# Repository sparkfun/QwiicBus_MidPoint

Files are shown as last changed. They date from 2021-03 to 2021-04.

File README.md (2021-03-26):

SparkFun QwiicBus MidPoint
========================================

SparkFun QwiicBus MidPoint (https://www.sparkfun.com/products/18000)

[*SparkFun QwiicBus MidPoint (COM-18000)*](https://www.sparkfun.com/products/18000)

The SparkFun QwiicBus MidPoint works in tandem with the [SparkFun QwiicBus EndPoint](https://www.sparkfun.com/products/16988) to drop in I<sup>2</sup>C connections into a long-distance wired differential I<sup>2</sup>C bus. 
Featuring the PCA9615, the MidPoint translates a standard two-wire I<sup>2</sup>C signal to a 4-wire differential signal to allow long-distance and/or isolated wired buses. The board also includes a buck regulator that can be enabled to combat voltage drop over long distances as well as deliver more current to attached devices.

Repository Contents
-------------------

* **/Hardware** - Eagle design files (.brd, .sch)
* **/Production** - Production panel files (.brd)

Documentation
--------------
* **[Hookup Guide](https://learn.sparkfun.com/tutorials/sparkfun-qwiicbus-hookup-guide)** - Basic hookup guide for the SparkFun QwiicBus (MidPoint and EndPoint).

Product Versions
----------------
* [COM-18000](https://www.sparkfun.com/products/18000)- Initial QwiicBus MidPoint release
* [COM-16988](https://www.sparkfun.com/products/16988) - QwiicBus EndPoint initial release
* [KIT-17250](https://www.sparkfun.com/products/17250) - The SparkFun QwiicBus Kit includes 2 EndPoints, 1 MidPoint and a pair of Ethernet cables to get started with the QwiicBus.

License Information
-------------------

This product is _**open source**_! 

Please review the LICENSE.md file for license information. 

If you have any questions or concerns on licensing, please contact technical support on our [SparkFun forums](https://forum.sparkfun.com/viewforum.php?f=152).

Distributed as-is; no warranty is given.

- Your friends at SparkFun.

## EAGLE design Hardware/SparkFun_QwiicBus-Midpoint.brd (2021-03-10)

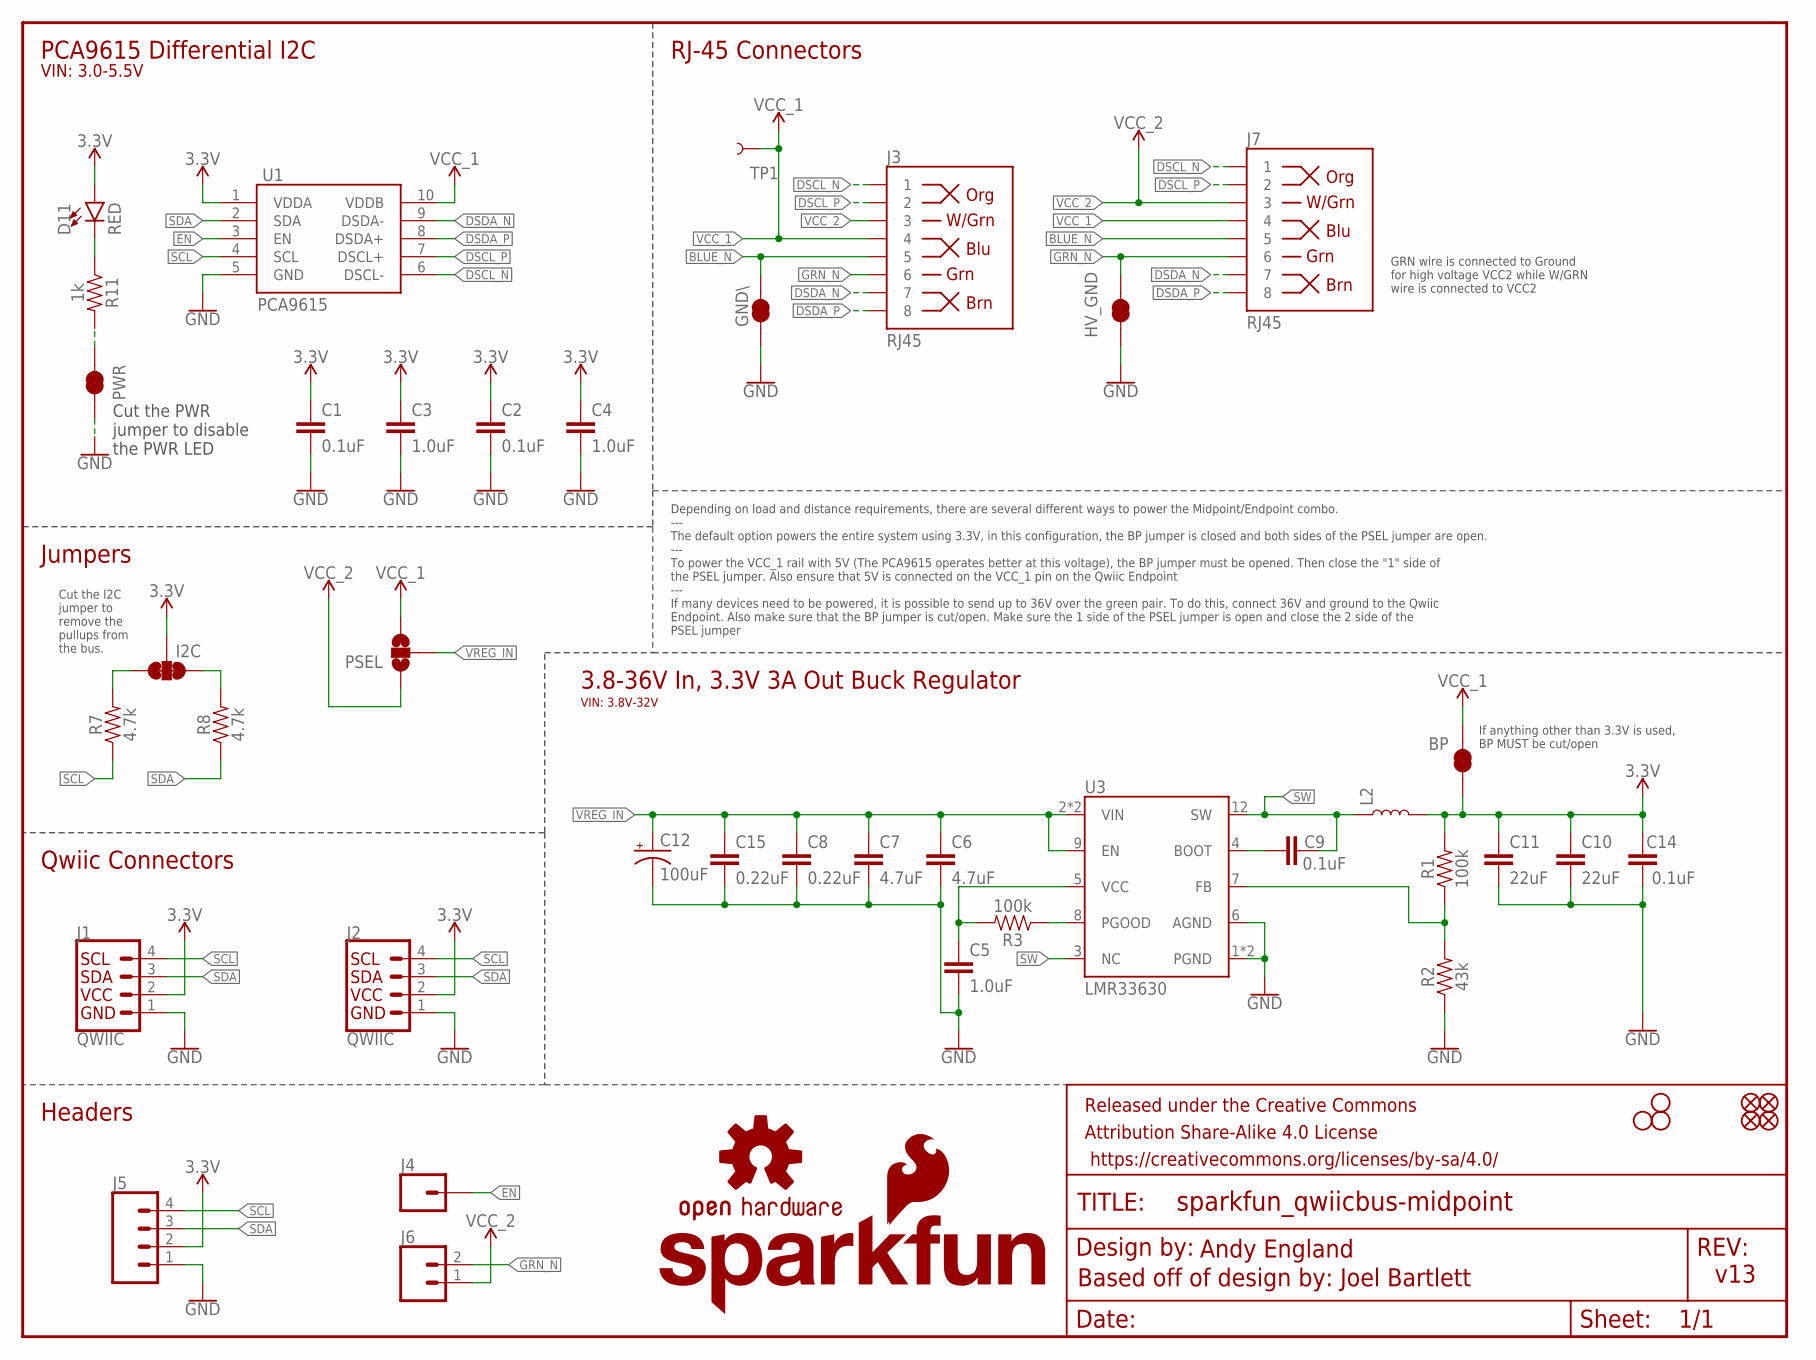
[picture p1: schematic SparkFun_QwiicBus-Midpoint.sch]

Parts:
BP: JUMPER-SMT_2_NC_TRACE_SILK; SMT-JUMPER_2_NC_TRACE_SILK
C1, C2, C9, C14: 0.1uF; 0603
C3, C4, C5: 1.0uF; 0603
C6, C7: 4.7uF; 0805
C8, C15: 0.22uF; 0603
C10, C11: 22uF; 1210
C12: 100uF; 8X10.5
D11: RED; LED-0603
FD1, FD2, FD3, FD4: FIDUCIALUFIDUCIAL; FIDUCIAL-MICRO
FRAME1: FRAME-LETTER; CREATIVE_COMMONS
GND\: JUMPER-SMT_2_NC_TRACE_SILK; SMT-JUMPER_2_NC_TRACE_SILK
H2, H3, H4: STAND-OFF
HV_GND: JUMPER-SMT_2_NC_TRACE_SILK; SMT-JUMPER_2_NC_TRACE_SILK
I2C: JUMPER-SMT_3_2-NC_TRACE_SILK; SMT-JUMPER_3_2-NC_TRACE_SILK
J1, J2: QWIIC; JST04_1MM_RA
J3, J7: RJ45; RJ45-8
J4: CONN_01PTH_NO_SILK_YES_STOP; 1X01_NO_SILK
J5: CONN_041X04_NO_SILK; 1X04_NO_SILK
J6: CONN_021X02_NO_SILK; 1X02_NO_SILK
L2: 2.2uH; INDUCTOR_5X5MM
LOGO1: OSHW-LOGOM; OSHW-LOGO-M
LOGO3: SFE_LOGO_FLAME.2_INCH; SFE_LOGO_FLAME_.2
LOGO4: SFE_LOGO_NAME_FLAME.1_INCH; SFE_LOGO_NAME_FLAME_.1
PSEL: JUMPER-SMT_3_NO_SILK; SMT-JUMPER_3_NO_SILK
PWR: JUMPER-SMT_2_NC_TRACE_SILK; SMT-JUMPER_2_NC_TRACE_SILK
R1, R3: 100k; 0603
R2: 43k; 0603
R7, R8: 4.7k; 0603
R11: 1k; 0603
TP1: TEST-POINT3; PAD.03X.03
U1: PCA9615; TSSOP10
U3: LMR33630; VQFN-HR-12

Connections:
3.3V: BP.1, C1.1, C2.1, C3.1, C4.1, C10.1, C11.1, C14.1, D11.A, I2C.2, J1.2, J2.2, J5.2, L2.P$2 (2), R1.2, U1.1 (VDDA)
BLUE_N: GND\.2, J3.5, J7.5
DSCL_N: J3.1, J7.1, U1.6 (DSCL-)
DSCL_P: J3.2, J7.2, U1.7 (DSCL+)
DSDA_N: J3.7, J7.7, U1.9 (DSDA-)
DSDA_P: J3.8, J7.8, U1.8 (DSDA+)
EN: J4.1, U1.3 (EN)
GND: C1.2, C2.2, C3.2, C4.2, C5.2, C6.2, C7.2, C8.2, C10.2, C11.2, C12.-, C14.2, C15.2, GND\.1, HV_GND.1, J1.1, J2.1, J5.1, PWR.1, R2.1, U1.5 (GND), U3.1 (PGND), U3.6 (AGND), U3.11 (PGND)
GRN_N: HV_GND.2, J3.6, J6.2, J7.6
unnamed: C9.1, U3.4 (BOOT)
unnamed: I2C.1, R8.2
unnamed: I2C.3, R7.2
unnamed: R1.1, R2.2, U3.7 (FB)
unnamed: R3.1, U3.8 (PGOOD)
unnamed: C5.1, R3.2, U3.5 (VCC)
unnamed: D11.C, R11.1
unnamed: PWR.2, R11.2
SCL: J1.4, J2.4, J5.4, R7.1, U1.4 (SCL)
SDA: J1.3, J2.3, J5.3, R8.1, U1.2 (SDA)
SW: C9.2, L2.P$1 (1), U3.3 (NC), U3.12 (SW)
VCC_1: BP.2, J3.4, J7.4, PSEL.3, TP1.P$1, U1.10 (VDDB)
VCC_2: J3.3, J6.1, J7.3, PSEL.1
VREG_IN: C6.1, C7.1, C8.1, C12.+, C15.1, PSEL.2, U3.2 (VIN), U3.9 (EN), U3.10 (VIN)

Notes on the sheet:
Andy England
PCA9615 Differential I2C
Qwiic Connectors
v13
Cut the I2C jumper to remove the pullups from the bus.
Headers
Jumpers
RJ-45 Connectors
Based off of design by: Joel Bartlett
Cut the PWR jumper to disable the PWR LED
3.8-36V In, 3.3V 3A Out Buck Regulator
VIN: 3.8V-32V
Depending on load and distance requirements, there are several different ways to power the Midpoint/Endpoint combo. --- The default option powers the entire system using 3.3V, in this configuration, the BP jumper is closed and both sides of the PSEL jumper are open. --- To power the VCC_1 rail with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
VIN: 3.0-5.5V
GRN wire is connected to Ground for high voltage VCC2 while W/GRN wire is connected to VCC2
If anything other than 3.3V is used, BP MUST be cut/open

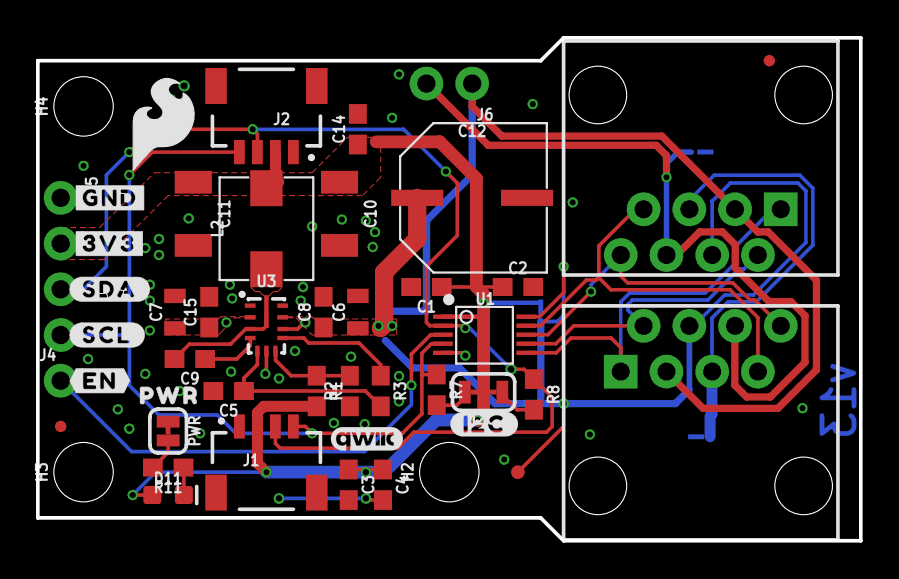
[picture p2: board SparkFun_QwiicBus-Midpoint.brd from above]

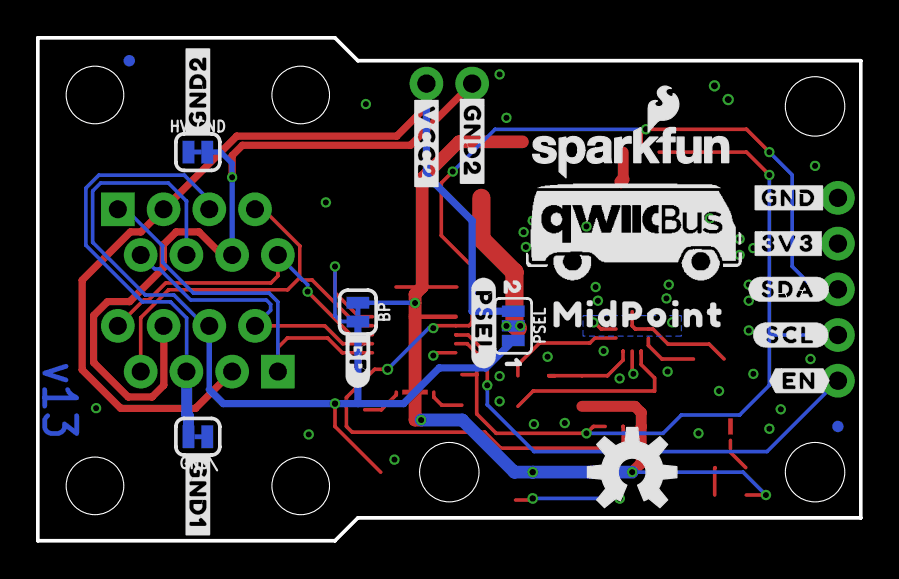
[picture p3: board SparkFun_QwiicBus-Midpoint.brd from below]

Board: 2 copper layers, 45.7 x 27.9 mm, 73 parts (23 on the bottom side), 23 nets.

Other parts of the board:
U$1, U$7: #GND#0
U$2, U$8: #3V3#0
U$3, U$9: #SDA#0
U$4, U$10: #SCL#0
U$5: #BP#0
U$6, U$12: #EN#0
U$11, U$24: #GND2#0
U$13: #I2C#0
U$14: #GND1#0
U$15: QWIICBUS#WORKING#LOGO#JPG
U$16: #VCC2#0
U$17: #PSEL#0
U$18: 10
U$19: 20
U$20: ORDERING_INSTRUCTIONS
U$22: QWIIC_4MM
U$23: PWR0
U$30: MIDPOINT0

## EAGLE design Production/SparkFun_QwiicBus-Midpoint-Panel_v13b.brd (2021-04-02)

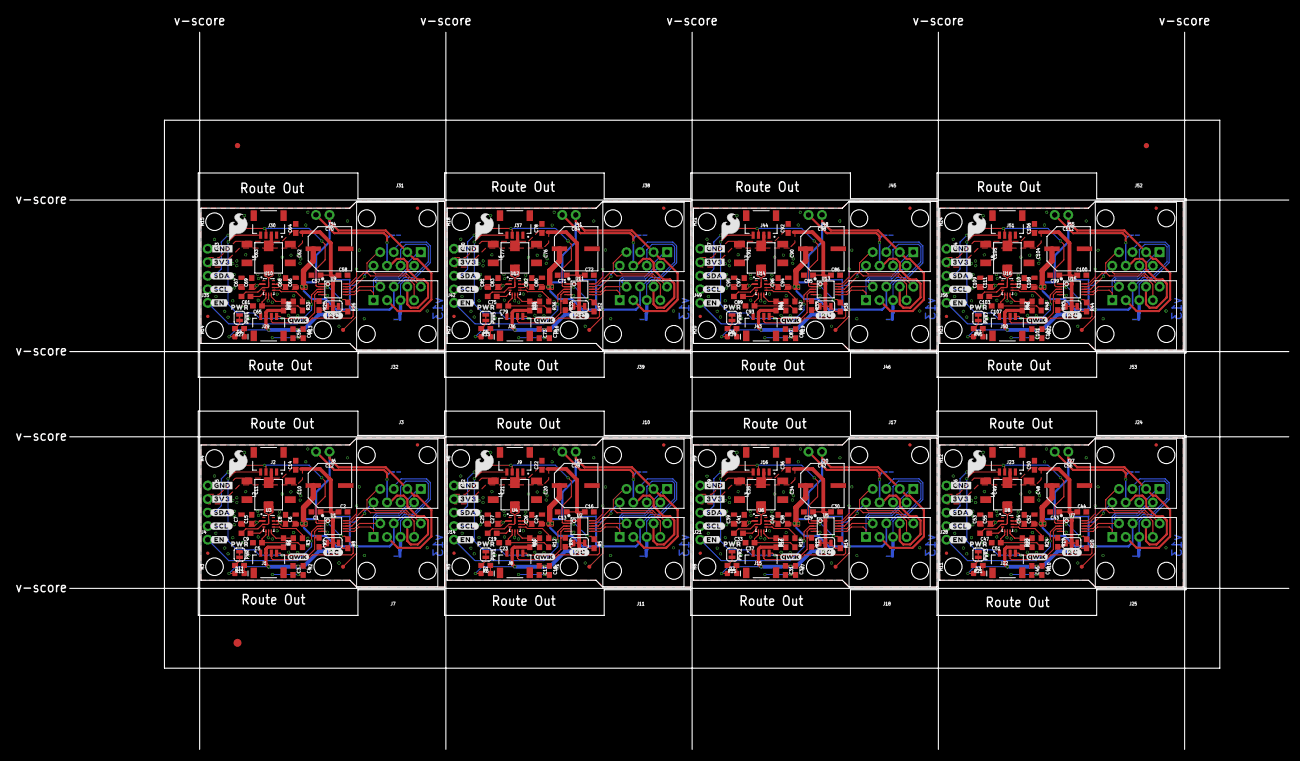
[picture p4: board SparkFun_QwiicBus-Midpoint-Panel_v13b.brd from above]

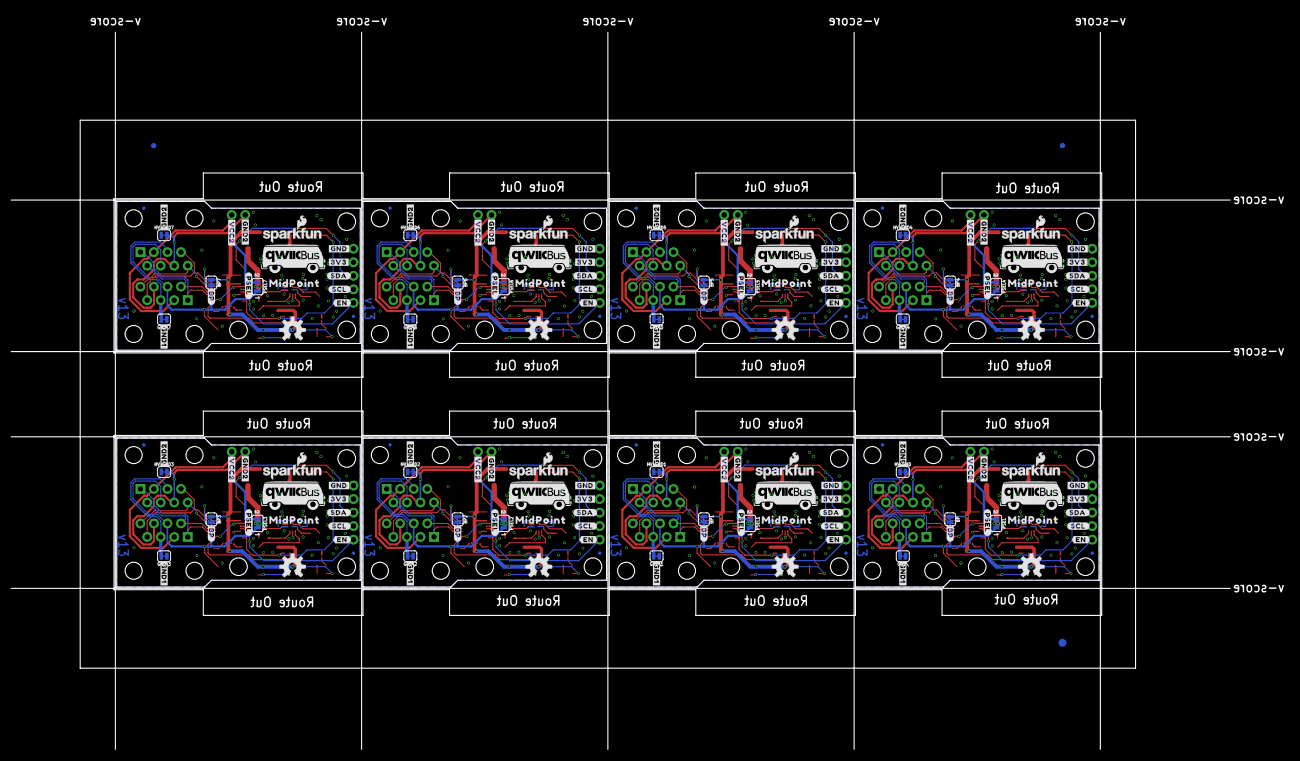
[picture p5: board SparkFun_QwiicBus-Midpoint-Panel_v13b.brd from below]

Board: 2 copper layers, 228.9 x 134.6 mm, 574 parts (187 on the bottom side), 184 nets.

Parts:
BP, BP1, BP2, BP3, BP4, BP5, BP6, BP7: JUMPER-SMT_2_NC_TRACE_SILK; SMT-JUMPER_2_NC_TRACE_SILK
C1, C2, C9, C13, C14, C16, C19, C22, C29, C30, C33, C36, C43, C44, C47, C50, C57, C58, C61, C64, C71, C72, C75, C78, C85, C86, C89, C92, C99, C100, C103, C106: 0.1uF; 0603
C3, C4, C5, C17, C18, C23, C31, C32, C37, C45, C46, C51, C59, C60, C65, C73, C74, C79, C87, C88, C93, C101, C102, C107: 1.0uF; 0603
C6, C7, C24, C25, C38, C39, C52, C53, C66, C67, C80, C81, C94, C95, C108, C109: 4.7uF; 0805
C8, C15, C26, C27, C40, C41, C54, C55, C68, C69, C82, C83, C96, C97, C110, C111: 0.22uF; 0603
C10, C11, C20, C21, C34, C35, C48, C49, C62, C63, C76, C77, C90, C91, C104, C105: 22uF; 1210
C12, C28, C42, C56, C70, C84, C98, C112: 100uF; 8X10.5
D1, D2, D3, D4, D5, D6, D7, D11: RED; LED-0603
E$1, E$2, E$3, E$4: FIDUCIAL-1X2
E$5, E$6: FIDUCIAL-1.5X3
FD1, FD2, FD3, FD4, FD5, FD6, FD7, FD8, FD9, FD10, FD11, FD12, FD13, FD14, FD15, FD16, FD17, FD18, FD19, FD20, FD21, FD22, FD23, FD24, FD25, FD26, FD27, FD28, FD29, FD30, FD31, FD32: FIDUCIALUFIDUCIAL; FIDUCIAL-MICRO
GND\, GND\1, GND\2, GND\3, GND\4, GND\5, GND\6, GND\7: JUMPER-SMT_2_NC_TRACE_SILK; SMT-JUMPER_2_NC_TRACE_SILK
H1, H2, H3, H4, H5, H6, H7, H8, H9, H10, H11, H12, H13, H14, H15, H16, H17, H18, H19, H20, H21, H22, H23, H24: STAND-OFF
HV_GND, HV_GND1, HV_GND2, HV_GND3, HV_GND4, HV_GND5, HV_GND6, HV_GND7: JUMPER-SMT_2_NC_TRACE_SILK; SMT-JUMPER_2_NC_TRACE_SILK
I2C, I2C1, I2C2, I2C3, I2C4, I2C5, I2C6, I2C7: JUMPER-SMT_3_2-NC_TRACE_SILK; SMT-JUMPER_3_2-NC_TRACE_SILK
J1, J2, J8, J9, J15, J16, J22, J23, J29, J30, J36, J37, J43, J44, J50, J51: QWIIC; JST04_1MM_RA
J3, J7, J10, J11, J17, J18, J24, J25, J31, J32, J38, J39, J45, J46, J52, J53: RJ45; RJ45-8
J4, J14, J21, J28, J35, J42, J49, J56: 1X01_NO_SILK
J5, J12, J19, J26, J33, J40, J47, J54: 1X04_NO_SILK
J6, J13, J20, J27, J34, J41, J48, J55: 1X02_NO_SILK
L1, L2, L3, L4, L5, L6, L7, L8: 2.2uH; INDUCTOR_5X5MM
LOGO1, LOGO2, LOGO7, LOGO10, LOGO13, LOGO16, LOGO19, LOGO22: OSHW-LOGOM; OSHW-LOGO-M
LOGO3, LOGO5, LOGO8, LOGO11, LOGO14, LOGO17, LOGO20, LOGO23: SFE_LOGO_FLAME.2_INCH; SFE_LOGO_FLAME_.2
LOGO4, LOGO6, LOGO9, LOGO12, LOGO15, LOGO18, LOGO21, LOGO24: SFE_LOGO_NAME_FLAME.1_INCH; SFE_LOGO_NAME_FLAME_.1
PSEL, PSEL1, PSEL2, PSEL3, PSEL4, PSEL5, PSEL6, PSEL7: JUMPER-SMT_3_NO_SILK; SMT-JUMPER_3_NO_SILK
PWR, PWR1, PWR2, PWR3, PWR4, PWR5, PWR6, PWR7: JUMPER-SMT_2_NC_TRACE_SILK; SMT-JUMPER_2_NC_TRACE_SILK
R1, R3, R9, R12, R16, R18, R22, R24, R28, R30, R34, R36, R40, R42, R46, R48: 100k; 0603
R2, R10, R17, R23, R29, R35, R41, R47: 43k; 0603
R4, R5, R7, R8, R13, R14, R19, R20, R25, R26, R31, R32, R37, R38, R43, R44: 4.7k; 0603
R6, R11, R15, R21, R27, R33, R39, R45: 1k; 0603
TP1, TP2, TP3, TP4, TP5, TP6, TP7, TP8: TEST-POINT3; PAD.03X.03
U1, U2, U5, U7, U9, U11, U13, U15: PCA9615; TSSOP10
U3, U4, U6, U8, U10, U12, U14, U16: LMR33630; VQFN-HR-12
U$1, U$7, U$20, U$28, U$47, U$52, U$70, U$75, U$93, U$98, U$116, U$121, U$139, U$144, U$162, U$167: #GND#0
U$2, U$8, U$21, U$29, U$48, U$53, U$71, U$76, U$94, U$99, U$117, U$122, U$140, U$145, U$163, U$168: #3V3#0
U$3, U$9, U$25, U$31, U$49, U$54, U$72, U$77, U$95, U$100, U$118, U$123, U$141, U$146, U$164, U$169: #SDA#0
U$4, U$10, U$26, U$32, U$50, U$55, U$73, U$78, U$96, U$101, U$119, U$124, U$142, U$147, U$165, U$170: #SCL#0
U$5, U$46, U$69, U$92, U$115, U$138, U$161, U$184: #BP#0
U$6, U$12, U$27, U$33, U$51, U$56, U$74, U$79, U$97, U$102, U$120, U$125, U$143, U$148, U$166, U$171: #EN#0
U$11, U$24, U$40, U$44, U$63, U$67, U$86, U$90, U$109, U$113, U$132, U$136, U$155, U$159, U$178, U$182: #GND2#0
U$13, U$38, U$61, U$84, U$107, U$130, U$153, U$176: #I2C#0
U$14, U$45, U$68, U$91, U$114, U$137, U$160, U$183: #GND1#0
U$15, U$37, U$60, U$83, U$106, U$129, U$152, U$175: QWIICBUS#WORKING#LOGO#JPG
U$16, U$39, U$62, U$85, U$108, U$131, U$154, U$177: #VCC2#0
U$17, U$41, U$64, U$87, U$110, U$133, U$156, U$179: #PSEL#0
U$18, U$42, U$65, U$88, U$111, U$134, U$157, U$180: 10
U$19, U$43, U$66, U$89, U$112, U$135, U$158, U$181: 20
U$22, U$34, U$57, U$80, U$103, U$126, U$149, U$172: QWIIC_4MM
U$23, U$35, U$58, U$81, U$104, U$127, U$150, U$173: PWR0
U$30, U$36, U$59, U$82, U$105, U$128, U$151, U$174: MIDPOINT0

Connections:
3.3V: BP.1, C1.1, C2.1, C3.1, C4.1, C10.1, C11.1, C14.1, D11.A, I2C.2, J1.2, J2.2, J5.2, L2.P$2, R1.2, U1.1
3.3V1: BP1.1, C13.1, C16.1, C17.1, C18.1, C20.1, C21.1, C22.1, D1.A, I2C1.2, J8.2, J9.2, J12.2, L1.P$2, R9.2, U2.1
3.3V2: BP2.1, C29.1, C30.1, C31.1, C32.1, C34.1, C35.1, C36.1, D2.A, I2C2.2, J15.2, J16.2, J19.2, L3.P$2, R16.2, U5.1
3.3V3: BP3.1, C43.1, C44.1, C45.1, C46.1, C48.1, C49.1, C50.1, D3.A, I2C3.2, J22.2, J23.2, J26.2, L4.P$2, R22.2, U7.1
3.3V4: BP4.1, C57.1, C58.1, C59.1, C60.1, C62.1, C63.1, C64.1, D4.A, I2C4.2, J29.2, J30.2, J33.2, L5.P$2, R28.2, U9.1
3.3V5: BP5.1, C71.1, C72.1, C73.1, C74.1, C76.1, C77.1, C78.1, D5.A, I2C5.2, J36.2, J37.2, J40.2, L6.P$2, R34.2, U11.1
3.3V6: BP6.1, C85.1, C86.1, C87.1, C88.1, C90.1, C91.1, C92.1, D6.A, I2C6.2, J43.2, J44.2, J47.2, L7.P$2, R40.2, U13.1
3.3V7: BP7.1, C99.1, C100.1, C101.1, C102.1, C104.1, C105.1, C106.1, D7.A, I2C7.2, J50.2, J51.2, J54.2, L8.P$2, R46.2, U15.1
BLUE_N: GND\.2, J3.5, J7.5
BLUE_N1: GND\1.2, J10.5, J11.5
BLUE_N2: GND\2.2, J17.5, J18.5
BLUE_N3: GND\3.2, J24.5, J25.5
BLUE_N4: GND\4.2, J31.5, J32.5
BLUE_N5: GND\5.2, J38.5, J39.5
BLUE_N6: GND\6.2, J45.5, J46.5
BLUE_N7: GND\7.2, J52.5, J53.5
DSCL_N: J3.1, J7.1, U1.6
DSCL_N1: J10.1, J11.1, U2.6
DSCL_N2: J17.1, J18.1, U5.6
DSCL_N3: J24.1, J25.1, U7.6
DSCL_N4: J31.1, J32.1, U9.6
DSCL_N5: J38.1, J39.1, U11.6
DSCL_N6: J45.1, J46.1, U13.6
DSCL_N7: J52.1, J53.1, U15.6
DSCL_P: J3.2, J7.2, U1.7
DSCL_P1: J10.2, J11.2, U2.7
DSCL_P2: J17.2, J18.2, U5.7
DSCL_P3: J24.2, J25.2, U7.7
DSCL_P4: J31.2, J32.2, U9.7
DSCL_P5: J38.2, J39.2, U11.7
DSCL_P6: J45.2, J46.2, U13.7
DSCL_P7: J52.2, J53.2, U15.7
DSDA_N: J3.7, J7.7, U1.9
DSDA_N1: J10.7, J11.7, U2.9
DSDA_N2: J17.7, J18.7, U5.9
DSDA_N3: J24.7, J25.7, U7.9
DSDA_N4: J31.7, J32.7, U9.9
DSDA_N5: J38.7, J39.7, U11.9
DSDA_N6: J45.7, J46.7, U13.9
DSDA_N7: J52.7, J53.7, U15.9
DSDA_P: J3.8, J7.8, U1.8
DSDA_P1: J10.8, J11.8, U2.8
DSDA_P2: J17.8, J18.8, U5.8
DSDA_P3: J24.8, J25.8, U7.8
DSDA_P4: J31.8, J32.8, U9.8
DSDA_P5: J38.8, J39.8, U11.8
DSDA_P6: J45.8, J46.8, U13.8
DSDA_P7: J52.8, J53.8, U15.8
EN: J4.1, U1.3
EN1: J14.1, U2.3
EN2: J21.1, U5.3
EN3: J28.1, U7.3
EN4: J35.1, U9.3
EN5: J42.1, U11.3
EN6: J49.1, U13.3
EN7: J56.1, U15.3
GND: C1.2, C2.2, C3.2, C4.2, C5.2, C6.2, C7.2, C8.2, C10.2, C11.2, C12.-, C14.2, C15.2, GND\.1, HV_GND.1, J1.1, J2.1, J5.1, PWR.1, R2.1, U1.5, U3.1, U3.6, U3.11
GND1: C13.2, C16.2, C17.2, C18.2, C20.2, C21.2, C22.2, C23.2, C24.2, C25.2, C26.2, C27.2, C28.-, GND\1.1, HV_GND1.1, J8.1, J9.1, J12.1, PWR1.1, R10.1, U2.5, U4.1, U4.6, U4.11
GND2: C29.2, C30.2, C31.2, C32.2, C34.2, C35.2, C36.2, C37.2, C38.2, C39.2, C40.2, C41.2, C42.-, GND\2.1, HV_GND2.1, J15.1, J16.1, J19.1, PWR2.1, R17.1, U5.5, U6.1, U6.6, U6.11
GND3: C43.2, C44.2, C45.2, C46.2, C48.2, C49.2, C50.2, C51.2, C52.2, C53.2, C54.2, C55.2, C56.-, GND\3.1, HV_GND3.1, J22.1, J23.1, J26.1, PWR3.1, R23.1, U7.5, U8.1, U8.6, U8.11
GND4: C57.2, C58.2, C59.2, C60.2, C62.2, C63.2, C64.2, C65.2, C66.2, C67.2, C68.2, C69.2, C70.-, GND\4.1, HV_GND4.1, J29.1, J30.1, J33.1, PWR4.1, R29.1, U9.5, U10.1, U10.6, U10.11
GND5: C71.2, C72.2, C73.2, C74.2, C76.2, C77.2, C78.2, C79.2, C80.2, C81.2, C82.2, C83.2, C84.-, GND\5.1, HV_GND5.1, J36.1, J37.1, J40.1, PWR5.1, R35.1, U11.5, U12.1, U12.6, U12.11
GND6: C85.2, C86.2, C87.2, C88.2, C90.2, C91.2, C92.2, C93.2, C94.2, C95.2, C96.2, C97.2, C98.-, GND\6.1, HV_GND6.1, J43.1, J44.1, J47.1, PWR6.1, R41.1, U13.5, U14.1, U14.6, U14.11
GND7: C99.2, C100.2, C101.2, C102.2, C104.2, C105.2, C106.2, C107.2, C108.2, C109.2, C110.2, C111.2, C112.-, GND\7.1, HV_GND7.1, J50.1, J51.1, J54.1, PWR7.1, R47.1, U15.5, U16.1, U16.6, U16.11
GRN_N: HV_GND.2, J3.6, J6.2, J7.6
GRN_N1: HV_GND1.2, J10.6, J11.6, J13.2
GRN_N2: HV_GND2.2, J17.6, J18.6, J20.2
GRN_N3: HV_GND3.2, J24.6, J25.6, J27.2
GRN_N4: HV_GND4.2, J31.6, J32.6, J34.2
GRN_N5: HV_GND5.2, J38.6, J39.6, J41.2
GRN_N6: HV_GND6.2, J45.6, J46.6, J48.2
GRN_N7: HV_GND7.2, J52.6, J53.6, J55.2
unnamed: C9.1, U3.4
unnamed: I2C1.1, R5.2
unnamed: I2C.1, R8.2
unnamed: I2C.3, R7.2
unnamed: I2C1.3, R4.2
unnamed: R1.1, R2.2, U3.7
unnamed: R3.1, U3.8
unnamed: D1.C, R6.1
unnamed: C5.1, R3.2, U3.5
unnamed: PWR1.2, R6.2
unnamed: C19.1, U4.4
unnamed: R9.1, R10.2, U4.7
unnamed: D11.C, R11.1
unnamed: PWR.2, R11.2
unnamed: R12.1, U4.8
unnamed: C23.1, R12.2, U4.5
unnamed: I2C2.1, R14.2
unnamed: I2C2.3, R13.2
unnamed: D2.C, R15.1
unnamed: PWR2.2, R15.2
unnamed: C33.1, U6.4
unnamed: R16.1, R17.2, U6.7
unnamed: R18.1, U6.8
unnamed: C37.1, R18.2, U6.5
unnamed: I2C3.1, R20.2
unnamed: I2C3.3, R19.2
unnamed: D3.C, R21.1
unnamed: PWR3.2, R21.2
unnamed: C47.1, U8.4
unnamed: R22.1, R23.2, U8.7
unnamed: R24.1, U8.8
unnamed: C51.1, R24.2, U8.5
unnamed: I2C4.1, R26.2
unnamed: I2C4.3, R25.2
unnamed: D4.C, R27.1
unnamed: PWR4.2, R27.2
unnamed: C61.1, U10.4
unnamed: R28.1, R29.2, U10.7
unnamed: R30.1, U10.8
unnamed: C65.1, R30.2, U10.5
unnamed: I2C5.1, R32.2
unnamed: I2C5.3, R31.2
unnamed: D5.C, R33.1
unnamed: PWR5.2, R33.2
unnamed: C75.1, U12.4
unnamed: R34.1, R35.2, U12.7
unnamed: R36.1, U12.8
unnamed: C79.1, R36.2, U12.5
unnamed: I2C6.1, R38.2
unnamed: I2C6.3, R37.2
unnamed: D6.C, R39.1
unnamed: PWR6.2, R39.2
unnamed: C89.1, U14.4
unnamed: R40.1, R41.2, U14.7
unnamed: R42.1, U14.8
unnamed: C93.1, R42.2, U14.5
unnamed: I2C7.1, R44.2
unnamed: I2C7.3, R43.2
unnamed: D7.C, R45.1
unnamed: PWR7.2, R45.2
unnamed: C103.1, U16.4
unnamed: R46.1, R47.2, U16.7
unnamed: R48.1, U16.8
unnamed: C107.1, R48.2, U16.5
SCL: J1.4, J2.4, J5.4, R7.1, U1.4
SCL1: J8.4, J9.4, J12.4, R4.1, U2.4
SCL2: J15.4, J16.4, J19.4, R13.1, U5.4
SCL3: J22.4, J23.4, J26.4, R19.1, U7.4
SCL4: J29.4, J30.4, J33.4, R25.1, U9.4
SCL5: J36.4, J37.4, J40.4, R31.1, U11.4
SCL6: J43.4, J44.4, J47.4, R37.1, U13.4
SCL7: J50.4, J51.4, J54.4, R43.1, U15.4
SDA: J1.3, J2.3, J5.3, R8.1, U1.2
SDA1: J8.3, J9.3, J12.3, R5.1, U2.2
SDA2: J15.3, J16.3, J19.3, R14.1, U5.2
SDA3: J22.3, J23.3, J26.3, R20.1, U7.2
SDA4: J29.3, J30.3, J33.3, R26.1, U9.2
SDA5: J36.3, J37.3, J40.3, R32.1, U11.2
SDA6: J43.3, J44.3, J47.3, R38.1, U13.2
SDA7: J50.3, J51.3, J54.3, R44.1, U15.2
SW: C9.2, L2.P$1, U3.3, U3.12
SW1: C19.2, L1.P$1, U4.3, U4.12
SW2: C33.2, L3.P$1, U6.3, U6.12
SW3: C47.2, L4.P$1, U8.3, U8.12
SW4: C61.2, L5.P$1, U10.3, U10.12
SW5: C75.2, L6.P$1, U12.3, U12.12
SW6: C89.2, L7.P$1, U14.3, U14.12
SW7: C103.2, L8.P$1, U16.3, U16.12
VCC_1: BP.2, J3.4, J7.4, PSEL.3, TP1.P$1, U1.10
VCC_2: J3.3, J6.1, J7.3, PSEL.1
VCC_3: BP1.2, J10.4, J11.4, PSEL1.3, TP2.P$1, U2.10
VCC_4: J10.3, J11.3, J13.1, PSEL1.1
VCC_5: BP2.2, J17.4, J18.4, PSEL2.3, TP3.P$1, U5.10
VCC_6: J17.3, J18.3, J20.1, PSEL2.1
VCC_7: BP3.2, J24.4, J25.4, PSEL3.3, TP4.P$1, U7.10
VCC_8: J24.3, J25.3, J27.1, PSEL3.1
VCC_9: BP4.2, J31.4, J32.4, PSEL4.3, TP5.P$1, U9.10
VCC_10: J31.3, J32.3, J34.1, PSEL4.1
VCC_11: BP5.2, J38.4, J39.4, PSEL5.3, TP6.P$1, U11.10
VCC_12: J38.3, J39.3, J41.1, PSEL5.1
VCC_13: BP6.2, J45.4, J46.4, PSEL6.3, TP7.P$1, U13.10
VCC_14: J45.3, J46.3, J48.1, PSEL6.1
VCC_15: BP7.2, J52.4, J53.4, PSEL7.3, TP8.P$1, U15.10
VCC_16: J52.3, J53.3, J55.1, PSEL7.1
VREG_IN: C6.1, C7.1, C8.1, C12.+, C15.1, PSEL.2, U3.2, U3.9, U3.10
VREG_IN1: C24.1, C25.1, C26.1, C27.1, C28.+, PSEL1.2, U4.2, U4.9, U4.10
VREG_IN2: C38.1, C39.1, C40.1, C41.1, C42.+, PSEL2.2, U6.2, U6.9, U6.10
VREG_IN3: C52.1, C53.1, C54.1, C55.1, C56.+, PSEL3.2, U8.2, U8.9, U8.10
VREG_IN4: C66.1, C67.1, C68.1, C69.1, C70.+, PSEL4.2, U10.2, U10.9, U10.10
VREG_IN5: C80.1, C81.1, C82.1, C83.1, C84.+, PSEL5.2, U12.2, U12.9, U12.10
VREG_IN6: C94.1, C95.1, C96.1, C97.1, C98.+, PSEL6.2, U14.2, U14.9, U14.10
VREG_IN7: C108.1, C109.1, C110.1, C111.1, C112.+, PSEL7.2, U16.2, U16.9, U16.10

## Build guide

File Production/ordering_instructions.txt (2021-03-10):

panel size, 199x119mm
PCB thickness, 1.6mm
number of layers, 2
soldermask color, Red
silkscreen color, White
oz copper, 2oz
finish, HASL lead free
stencils, top
pcs per panel, 8
min trace width, 0.2032mm / 0.0080in
min drill size, 0.3302mm / 0.0130in

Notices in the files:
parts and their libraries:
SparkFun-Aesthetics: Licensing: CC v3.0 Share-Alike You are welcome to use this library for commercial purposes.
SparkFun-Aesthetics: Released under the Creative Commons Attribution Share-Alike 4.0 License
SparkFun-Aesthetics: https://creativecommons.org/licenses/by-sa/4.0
